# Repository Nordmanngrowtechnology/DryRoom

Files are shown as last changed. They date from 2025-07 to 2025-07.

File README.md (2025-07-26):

# Arduino Nano ATmega328P (New Bootloader) Dry & Humidity control with relay and fan

---
Electricity can kill or seriously injure you. Work involving electricity should only be carried out by qualified personnel. This project is not an instruction manual. I assume no liability for damages.
---

In my case use Clion with platform.io for deploying this project below based on this setup.
https://docs.platformio.org/en/latest/boards/atmelavr/nanoatmega328new.html

Is not the right bootload selected given upload failure and notice warning in console output.

- Arduino Nano with ATmega328P
- 16Mhz Tact rate
- USB-C port
- Tow case fans with PWM
  - Case fan on chanel 9
  - Case fan on chanel 10

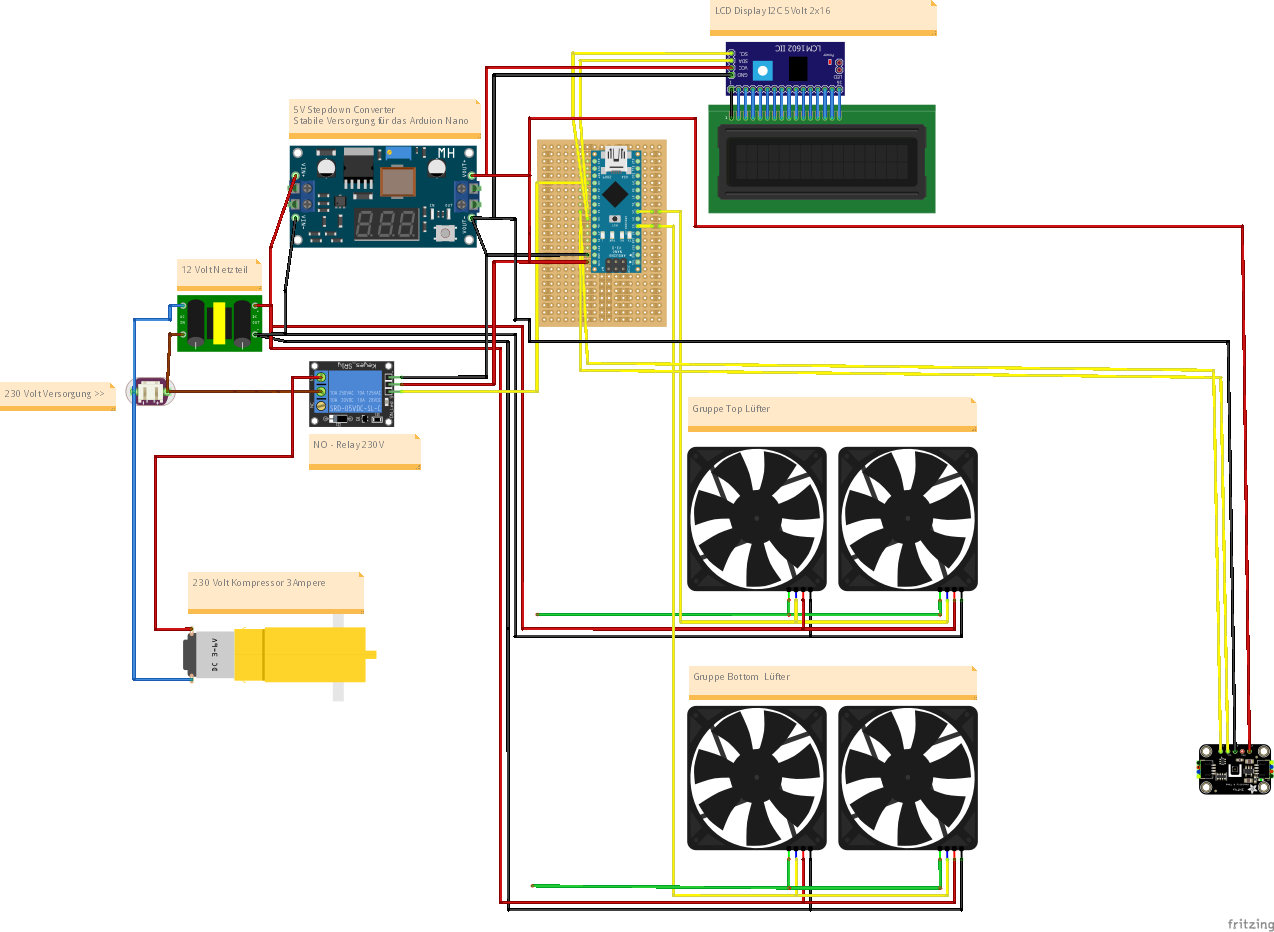
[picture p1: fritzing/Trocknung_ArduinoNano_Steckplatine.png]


# Generate 25kHz PWM signal with Arduino
Generate the right 25kHz signal for **tow** output pins is no problem with the Arduino Nano.
For this we update the internal hardware TIMER1 so we had the other timer for millis() or delay().  First we stop the interrupts, config the timer and ports and activate the interrupts.

#### Tow pins need tow conection

`TCCR1A |= (1 << COM1A1) | (1 << COM1B1);`

```
void setup() {
    cli(); // disable interrupts

    /*
     *  DEFINITION TIMER1 FOR ATMEL ATmega328P
     *  https://ww1.microchip.com/downloads/en/DeviceDoc/Atmel-7810-Automotive-Microcontrollers-ATmega328P_Datasheet.pdf
     *  https://www.mikrocontroller.net/articles/AVR-Tutorial:_Timer
    */

    // RESET  Clear Timer/Counter control registers
    TCNT1 = 0;
    TCCR1A = 0;
    TCCR1B = 0;

    // Set TOP value for 25kHz frequency (ICR1)
    ICR1 = 320; // Set TOP limiter to 320 >>> update OCR1A at TOP

    // REGISTER DEFINITION
    TCCR1A |= (1 << WGM11); // PWM, Phase Correct
    TCCR1B |= (1 << WGM13); // The phase correct Pulse Width Modulation or phase correct PWM mode (WGM13:0 = 1
    TCCR1B |= (1 << CS10); // clkI/O/1 (No prescaling)

    // Need COM1A1 and COM1B1 for tow pin output . Clear OC1A/OC1B on compare match
    TCCR1A |= (1 << COM1A1) | (1 << COM1B1); // Clear OC1A/OC1B on Compare match when down counting set output to low level

    // Set Arduino Nano pins to output with Data Direction Registers B (Arduino Pin 9 is PB1), (Arduino Pin 10 is PB2) is a part of Port B
    DDRB |= (1 << 1) | (1 << 2); // set as OUTPUT

    // Set RELAY pin PD5 is a part off Port D
    DDRD |= (1 << 5);   // set as OUTPUT
    PORTD &= ~(1 << 5); // set to LOW

    // end
    sei(); // allow interrupts
```

## Attention*
Minimum fan PWM signal in my case 5% duty cycle. Use Paired Timer TC1 on pin 9 & 10. *Standard relays aren't sufficient. To switch high power, proper relays are needed.

## Hardware to test the dry room controller

Important is we use Timer1 >> and the located output to OC1A, OC1B by Arduino Nano with ATmega328P. 

| Pin | Method | Hard. | More. |
|-----|---|---|---|
| 10  | analogWrite()  | Top FAN | PWM |
| 9 | analogWrite()  | Bottom FAN | PWM |
| 18  | readBytes() | SHT 45 | SDA 0x44 |
| 19  | readBytes() | SHT 45 | SCL 0x44 |
| 18  | readBytes() | Display 16*2 | SDA 0x27 |
| 19  | readBytes() | Display 16*2 | SCL 0x27 |
| 14  | readAnalog() | FAN-Tacho Top | |
| 15  | readAnalog() | FAN-Tacho Bottom | |
| 5 | digitalWrite() | Relay SPDT, **30 A**, SLA-05VDC-SL-C  | attention* |

*Standard relays aren't sufficient. To switch high power, proper relays are needed.

# TODO
Add the real cooling sw profil non-public

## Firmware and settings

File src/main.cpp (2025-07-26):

// arduino lib
#include <Arduino.h>

// >>> ### --- SHT45 TEMPERATURE & HUMIDITY SENSOR --- ### >>>
// Cable black = SHIELD on Case
// Cable red = VDD 5V PIN_5V
// Cable green = SCL PIN_19  **A5
// Cable yellow = SDA PIN_18 **A4
// Cable black = GND PIN_GND
#include <ArtronShop_SHT45.h>
#include <Wire.h>
ArtronShop_SHT45 sensor(&Wire,
                        0x44); // default is right (&Wire, 0x44) SHT45-AD1B => I2C address 0x44
float temperature;
float humidity;
constexpr float MIN_TEMPERATURE = 17.0; // cooling stops
constexpr float MAX_TEMPERATURE = 19.0; // cooling starts
constexpr float MAX_HUMIDITY = 58.0;    // Circulation max speed
constexpr float MIN_HUMIDITY = 54.0;    // Below this value Circulation FAN_MINIMUM_DUTY_CYCLE

// >>> ### --- DISPLAY --- ### >>>
// Cable green = SCL PIN_19  **A5
// Cable yellow = SDA PIN_18 **A4
#include <LiquidCrystal_I2C.h> //Include lib
LiquidCrystal_I2C lcd(0x27, 16,
                      2); // set the LCD address to 0x27 for 16 chars and 2 line display

// >>> ### --- COOLING_COMPRESSOR RELAY --- ### >>>
constexpr int COOLING_COMPRESSOR_PIN = 5; // Signal to SPDT, 30 A

/*
 * Configuration for the PWM fan signal and the circulation setup.
 * Bind the pins
 */
struct Pin
{
    uint8_t pwmPin;
};

constexpr Pin FAN_PWM_PIN_TOP_FAN{10};         // 10
constexpr Pin FAN_PWM_PIN_BOTTOM_FAN{9};       // 9
constexpr uint8_t FAN_MINIMUM_DUTY_CYCLE = 7;  // The lowest PWM Duty Cycle the fank can look
                                               // in datasheet for your fan
constexpr uint8_t FAN_MAXIMAL_DUTY_CYCLE = 50; // Maximal Fan Speed
constexpr uint8_t CIRCULATION_SPREAD = 5;      // Circulation spread between pwm groups top fan bottom fan
bool fanOn = false;

// INT CONF
unsigned long previousMillis = 0;
unsigned long temp_interval = 30000; // 30 second temp_interval for checkup relay off?
unsigned long dry_interval = 180000; // 3 Minutes 180000ms

void setup()
{
    cli(); // disable interrupts

    /*
     *  FIND MORE INFORMATION HOW IT WORKS
     *
     *  DEFINITION TIMER1 FOR ATMEL ATmega328P
     *  https://ww1.microchip.com/downloads/en/DeviceDoc/Atmel-7810-Automotive-Microcontrollers-ATmega328P_Datasheet.pdf
     *  https://www.mikrocontroller.net/articles/AVR-Tutorial:_Timer
     *
     *
     *  CHANGE TIMER1 SETTINGS FOR 25kHz SIGNAL CALCULATION
     */

    // RESET  Clear Timer/Counter control registers
    TCNT1 = 0;
    TCCR1A = 0;
    TCCR1B = 0;

    // Set TOP value for 25kHz frequency (ICR1)
    ICR1 = 320; // Set TOP limiter to 320 >>> update OCR1A at TOP

    // REGISTER DEFINITION
    TCCR1A |= 1 << WGM11; // PWM, Phase Correct
    TCCR1B |= 1 << WGM13; // The phase correct Pulse Width Modulation or phase
                          // correct PWM mode (WGM13:0 = 1
    TCCR1B |= 1 << CS10;  // clkI/O/1 (No prescaling)

    // Need COM1A1 and COM1B1 for tow pin output . Clear OC1A/OC1B on compare
    // match
    TCCR1A |= 1 << COM1A1 | 1 << COM1B1;
    // Clear OC1A/OC1B on Compare match when down counting set output to low
    // level

    // Set Arduino Nano pins to output with Data Direction Registers B (Arduino
    // Pin 9 is PB1), (Arduino Pin 10 is PB2) is a part of Port B
    DDRB |= 1 << 1 | 1 << 2; // set as OUTPUT

    // Set RELAY pin PD5 is a part off Port D
    DDRD |= 1 << 5;     // set as OUTPUT
    PORTD &= ~(1 << 5); // set to LOW

    // end
    sei(); // allow interrupts

    // inti serial
    Serial.begin(9600);

    // Init the LCD-Display
    lcd.init();
    lcd.backlight();

    /*// Relay init the pin set it to "OUTPUT"
    pinMode(COOLING_COMPRESSOR_PIN, OUTPUT);
    digitalWrite(COOLING_COMPRESSOR_PIN, LOW);
    delay(15);*/

    // init wire chanel check SHT45 connected
    Wire.begin();
    while (!sensor.begin())
    {
        Serial.println("SHT45 notfound!");
        // add error to display
        lcd.print("SHT45 not found!");
        delay(2000);
    }
}

// overwrite default analogWrite function for pwm fan pins
void analogWrite(const Pin &pin, const uint8_t percent)
{
    if (pin.pwmPin == FAN_PWM_PIN_TOP_FAN.pwmPin)
    {
        OCR1A = map(percent, 0, 100, 0, ICR1);
    } // ICR1 320
    if (pin.pwmPin == FAN_PWM_PIN_BOTTOM_FAN.pwmPin)
    {
        OCR1B = map(percent, 0, 100, 0, ICR1);
    } // ICR1 320
}

void circulation(const uint8_t percent)
{

    if (percent - CIRCULATION_SPREAD <= FAN_MINIMUM_DUTY_CYCLE)
    {
        // minimum circulation
        analogWrite(FAN_PWM_PIN_TOP_FAN, FAN_MINIMUM_DUTY_CYCLE);
        analogWrite(FAN_PWM_PIN_BOTTOM_FAN, percent);
    }
    else
    {
        // calculated circulation
        analogWrite(FAN_PWM_PIN_TOP_FAN, percent - CIRCULATION_SPREAD);
        analogWrite(FAN_PWM_PIN_BOTTOM_FAN, percent);
    }

    // print
    Serial.print("Fan run ");
    Serial.print(percent);
    Serial.println("%");
    delay(1000);
}

// calculate the speed
uint8_t mySpeed(const float humi)
{

    if (humi <= MIN_HUMIDITY)
    {
        fanOn = true;
        return FAN_MINIMUM_DUTY_CYCLE;
    }

    constexpr float h_range = 100 - MIN_HUMIDITY;                            // 46
    constexpr int s_range = FAN_MAXIMAL_DUTY_CYCLE - FAN_MINIMUM_DUTY_CYCLE; // 44

    constexpr float part = s_range / h_range;

    const auto speed = static_cast<uint8_t>(humi - MIN_HUMIDITY * part + FAN_MINIMUM_DUTY_CYCLE);
    // 61 - 54 * 0.95 + 6;

    return speed; // 12
}

void loop()
{
    // time marker
    const unsigned long currentMillis = millis();

    if (sensor.measure())
    {
        const float temperature = sensor.temperature();
        const float humidity = sensor.humidity();
        const long speed = mySpeed(humidity);

        // serial output
        Serial.print("Temperature: ");
        Serial.print(temperature, 1);
        Serial.print(" *C\tHumidity: ");
        Serial.print(humidity, 1);
        Serial.print(" %RH");
        Serial.println();

        // TEMPERATURE IS HIGH COMPRESSOR RELAY ON
        if (temperature >= MAX_TEMPERATURE)
        {
            // start compressor
            digitalWrite(COOLING_COMPRESSOR_PIN, HIGH);
            Serial.println("Kühlung ON: ");
            lcd.setCursor(0, 0);
            lcd.print("Kuehlung ON");
            lcd.setCursor(0, 1);
            lcd.print(String("Temperatur: ") + String(temperature));
            delay(3000);
            lcd.clear();
            // Fan circulation on
            if (!fanOn)
            {
                fanOn = true;
                circulation(speed);
            }
        }

        // TEMPERATUR IS COOLING DOWN
        if (temperature <= MIN_TEMPERATURE)
        {
            // show important massage
            Serial.println("Kühlung ON: ");
            lcd.setCursor(0, 0);
            lcd.print("Kuehlung ON");
            lcd.setCursor(0, 1);
            lcd.print(String("Temperatur: ") + String(temperature));
            delay(3000);
            lcd.clear();
            // Fan circulation on
            if (!fanOn)
            {
                fanOn = true;
                circulation(speed);
            }
        }

        // TEMPERATURE IS LOW COMPRESSOR RELAY OFF
        if (temperature <= MIN_TEMPERATURE)
        {
            // stop compressor
            digitalWrite(COOLING_COMPRESSOR_PIN, LOW);
            Serial.println("Kühlung OFF: ");
            lcd.setCursor(0, 0);
            lcd.print("Kuehlung OFF");
            lcd.setCursor(0, 1);
            lcd.print(String("Temperatur: ") + String(temperature));
            delay(3000);
            lcd.clear();
        }

        circulation(speed); // this funktion write to serial
        lcd.setCursor(0, 0);
        lcd.print(String("Humidity: ") + String(humidity));
        lcd.setCursor(0, 1);
        lcd.print("Fan Speed:" + String(speed));
        delay(3000);
        lcd.clear();

        // set the time
        previousMillis = currentMillis;
    }
    else
    {
        // sensor connection error run fan by default low
        fanOn = true;
        circulation(FAN_MINIMUM_DUTY_CYCLE);
        // print out error message
        Serial.println("SHT45 read error");
        lcd.setCursor(0, 0);
        lcd.print("SHT45 sensor read error");
        delay(5000);
    }
}

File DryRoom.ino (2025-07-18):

// arduino lib
#include <Arduino.h>

// >>> ### --- SHT45 TEMP & HUMIDY --- ### >>>
// Cable black = SHIELD on Case
// Cable red = VDD 5V PIN_5V
// Cable green = SCL PIN_19  **A5
// Cable yellow = SDA PIN_18 **A4
// Cable black = GND PIN_GND
#include <Wire.h>
#include <ArtronShop_SHT45.h>
ArtronShop_SHT45 sht45(&Wire, 0x44);  // SHT45-AD1B => I2C adress 0x44
float temp;
float humidity;

// >>> ### --- DISPLAY --- ### >>>
#include <LiquidCrystal_I2C.h>       //Include lib
LiquidCrystal_I2C lcd(0x27, 16, 2);  // set the LCD address to 0x27 for a 16 chars and 2 line display


// >>> ### --- REALY --- ### >>>
constexpr int RELAY_FREZZER_PIN = 9; // Signal to SPDT, 30 A
//constexpr int RELAY_CIRCULATION_PIN = 15;
#include "Relay.h"
Relay frezzer_motor(RELAY_FREZZER_PIN, true);  // constructor receives (pin, isNormallyOpen) true = Normally Open, false = Normally Closed
//Relay humy_circulation(RELAY_CIRCULATION_PIN, true);  // constructor receives (pin, isNormallyOpen) true = Normally Open, false = Normally Closed

// >>> ### --- PWM CASE FAN 25 kHz --- ### >>>
constexpr int PWM_FAN_TOP = 3;
constexpr int PWM_FAN_BOTTOM = 5;
constexpr int fan;
constexpr int speed;

// overwrite default analogWrite function for pwm fan pins
void analogWrite(const Pin &nPin, uint8_t percent) {
  if (nPin == PWM_FAN_TOP || nPin == PWM_FAN_BOTTOM) OCR1A = map(percent, 0, 100, 0, ICR1);
}

byte textLen;
void setup() {

  // reset the atmega timer on nano
  TCNT1 = 0;                                        // Count Increment or decrement TCNT1 by 1. set to 0
  TCCR1A = 0; TCCR1B = 0;                           // TCCR1 register to 0
  ICR1  = 320;                                      // counter limiter
  TCCR1B |= (1 << WGM13); TCCR1A |= (1 << WGM11);   // 16.4 Timer/Counter Clock Sources Register B (TCCR1B)
  TCCR1A |= (1 << COM1A1);                          // 16.2.1 Registers
  TCCR1B |= (1 << CS10);

  // inti serial
  Serial.begin(9600);

  // Init the LCD-Display
  lcd.init();
  lcd.backlight();

  // init wire chanel check SHT45 connectet
  Wire.begin();
  textLen = sizeof("SHT45 not found !") - 1;
  while (!sht45.begin()) {
    Serial.println("SHT45 not found !");
    // add error to display
    lcd.print("SHT45 not found !");
    // Scroll hidden text through entire row to the right outside the screen
    for (byte positionCounter = 0; positionCounter < textLen + 16; positionCounter++) {
      lcd.scrollDisplayRight();
      delay(500);
    }
  }

  // Relays intit the pins
  frezzer_motor.begin();
  //humy_circulation.begin();
}
void loop() {

  // Fan circulation low on
  fanSpeed(PWM_FAN_TOP, 10);
  fanSpeed(PWM_FAN_BOTTOM, 13);

  // test SHT45
  if (sht45.measure()) {
    Serial.print("Temperature: ");
    Serial.print(sht45.temperature(), 1);
    Serial.print(" *C\tHumidity: ");
    Serial.print(sht45.humidity(), 1);
    Serial.print(" %RH");
    Serial.println();

    // HANDLE TEMPARATUR
    temp = sht45.temperature();

    // temparature to hige
    if (temp > 18) {
      // run kompressor
      frezzer_motor.turnOn();
      lcd.setCursor(0, 0);
      lcd.print("Die Kuehlung ist eingeschaltet");
      lcd.setCursor(0, 1);
      lcd.print(String("Temparatur: ") + String(temp));

      // Fan circulation on
      fanSpeed(PWM_FAN_TOP, 50);
      fanSpeed(PWM_FAN_BOTTOM, 40);
    } else {
      // frezzer relay off
      frezzer_motor.turnOff();
      // show temp on display
    lcd.setCursor(0, 1);
    lcd.print(String("Temparatur: ") + String(temp));
    }

    delay(10000); // 10 second to next


    // HANDLE HUMIDITY
    humidity = sht45.humidity();

    if (humidity >= 58) {
      // WET: Fast fan circulation
      fanSpeed(PWM_FAN_TOP, 80);
      fanSpeed(PWM_FAN_BOTTOM, 70);
      // massage output
      lcd.setCursor(0, 0);
      lcd.print(String("Sehr feuchte Luft: ") + String(humidity));
      lcd.setCursor(0, 1);
      lcd.print("Luefter Cyrculation sehr schnell!");
    }
    else if (humidity > 55){
      // NORMAL: Modarate fan circulation
      fanSpeed(PWM_FAN_TOP, 50);
      fanSpeed(PWM_FAN_BOTTOM, 40);
      // massage output
      lcd.setCursor(0, 0);
      lcd.print(String("Die Luftfeuchtigkeit ist: ") + String(humidity));
      lcd.setCursor(0, 1);
      lcd.print("Lüfter laufen langsam.");
    }else{
    // DEFAULT: Slow fan cyrculation
    fanSpeed(PWM_FAN_TOP, 10);
    fanSpeed(PWM_FAN_BOTTOM, 13);
    // massage output
      lcd.setCursor(0, 0);
      lcd.print(String("Die Luftfeuchtigkeit ist: ") + String(humidity));
      lcd.setCursor(0, 1);
      lcd.print("Luefter laufen langsam.");
    }

    delay(10000); // 10 second to next


  
  } else {  //SHT read error
    Serial.println("SHT45 read error");
    lcd.setCursor(0, 0);
    lcd.print("SHT45 sensor read error");
  }
}
